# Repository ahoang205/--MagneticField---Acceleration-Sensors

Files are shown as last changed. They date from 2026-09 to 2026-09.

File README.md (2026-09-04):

# 🧭 Cảm Biến Từ Trường & Gia Tốc Đo Xa Không Dây (Low-Power Wireless Magnetic & Acceleration Sensing System)







Dự án thiết kế hệ thống phần cứng và phần mềm nhúng (Embedded IoT System) công suất thấp dùng để đo đạc, thu thập dữ liệu **Từ Trường 3 Trục** và **Gia Tốc / Góc Quay 6 Trục**, truyền dữ liệu đo từ xa qua mạng không dây **Wi-Fi Telemetry** về máy chủ giám sát.

---

## ⚡ Tính Năng Hệ Thống (Key Features)

- **Cảm Biến Từ Trường Độ Chính Xác Cao:** Tích hợp chip **MMC5983MA** (3-Axis Magnetometer) đo từ trường trái đất và phát hiện các biến đổi từ tính nhạy bén.
- **Cảm Biến Gia Tốc & Góc Quay Chuẩn Ô Tô:** Tích hợp IMU 6 trục **ASM330LHHTR** (Automotive Grade 6-axis IMU) đo gia tốc tuyến tính và vận tốc góc cực kỳ ổn định.
- **Khóa Mạch Công Suất Thấp (Low-Power Design):** Quản lý nguồn thông minh tối ưu điện năng tiêu thụ cho các thiết bị đo đạc chạy pin / năng lượng mặt trời.
- **Truyền Dữ Liệu Không Dây (Wi-Fi Telemetry):** Vi điều khiển **ESP32** đóng vai trò thu thập dữ liệu qua chuẩn truyền thông **I2C/SPI** và phát dữ liệu Telemetry liên tục qua Wi-Fi.

---

## 🧩 Sơ Đồ Khối Hệ Thống (System Architecture)

```mermaid
flowchart LR
    subgraph Sensors["Hệ Thống Cảm Biến"]
        S1["MMC5983MA (Từ Trường 3 Trục)"]
        S2["ASM330LHHTR (Gia Tốc & Gyro 6 Trục)"]
    end

    subgraph MCU["Xử Lý & Truyền Thông"]
        E1["ESP32 Microcontroller"]
        E2["Mạch Quản Lý Nguồn Năng Lượng Thấp"]
    end

    subgraph Output["Giám Sát Từ Xa"]
        W1["Mạng Wi-Fi Telemetry"]
        D1["Web Dashboard / Server Giám Sát"]
    end

    S1 -- "I2C Bus" --> E1
    S2 -- "I2C / SPI" --> E1
    E2 -- "Power Supply (3.3V)" --> E1
    E1 -- "UDP / MQTT / HTTP Telemetry" --> W1
    W1 --> D1
```

---

## 📊 Thông Số Kỹ Thuật (Specifications)

| Thông Số (Parameter) | Giá Trị (Value) | Ghi Chú (Notes) |
| :--- | :--- | :--- |
| **Vi Điều Khiển Main MCU** | `ESP32 / ESP32-WROOM-32` | Tích hợp Wi-Fi 802.11 b/g/n & Bluetooth |
| **Cảm Biến Từ Trường** | `MMC5983MA` | 0.5 mG resolution, ±8 Gauss FSR |
| **Cảm Biến IMU 6 Trục** | `ASM330LHHTR` | 3-axis Accel + 3-axis Gyro (Automotive) |
| **Chuẩn Truyền Thông Nối Tiếp** | `I2C (400kHz Fast Mode) / SPI` | Giao tiếp độ tin cậy cao |
| **Điện Áp Cấp (VCC)** | `3.3V DC` | Tích hợp LDO điện áp thấp |
| **Phần Mềm EDA Thiết Kế PCB** | `KiCad v6 / v7 / v8` | Sẵn file `.kicad_sch` & `.kicad_pcb` |

---

## 📂 Cấu Trúc Thư Mục Dự Án (Repository Structure)

```text
Magnetic_field_&_Acceleration_Sensors/
├── hardware/                         # Thiết kế phần cứng (Hardware EDA)
│   ├── schematics/                   # File bản vẽ sơ đồ nguyên lý PDF
│   │   └── schematic_Qcomment_24_12_25.pdf
│   ├── kicad/                        # Bộ file nguồn KiCad (.kicad_sch, .kicad_pcb, .kicad_pro)
│   │   ├── Low-Power Instrument.kicad_pcb
│   │   ├── Low-Power Instrument.kicad_sch
│   │   └── production/               # File Gerber gia công PCB, BOM, CPL
│   └── Dependencies/                 # Thư viện footprint & 3D STEP linh kiện
│       ├── ul_MMC5983MA/             # 3D Model & Footprints cảm biến từ trường
│       └── ul_ASM330LHHTR/           # 3D Model & Footprints cảm biến gia tốc
├── firmware/                         # Mã nguồn vi điều khiển kép (Dual MCU)
│   ├── stm32_firmware/               # Mã nguồn STM32L4xx HAL đọc mẫu cảm biến I2C/UART
│   │   ├── Core/Src/main.c           # Chương trình chính xử lý mẫu từ trường & IMU
│   │   └── supercap_test.ioc         # File cấu hình chân STM32CubeMX
│   └── esp32_wifi_telemetry/         # Mã nguồn ESP32 Arduino IDE
│       └── esp32_wifi_telemetry.ino  # Code Server Web 3D Dashboard & WebSocket Telemetry
├── docs/                             # Tài liệu kỹ thuật dự án
├── .gitignore                        # Cấu hình lọc file rác KiCad & IDE
├── LICENSE                           # Giấy phép bản quyền nguồn mở MIT
└── README.md                         # Tài liệu giới thiệu dự án
```

---

## 🛠️ Hướng Dẫn Cài Đặt & Nạp Code (Installation & Flashing Guide)

### 1. Mở & Chỉnh Sửa Phần Cứng (KiCad)
1. Cài đặt phần mềm [KiCad EDA v6+](https://www.kicad.org/).
2. Mở file `hardware/kicad/Low-Power Instrument.kicad_pro` để xem sơ đồ nguyên lý và thiết kế mạch PCB 2 lớp.

### 2. Nạp Code Cho Vi Điều Khiển ESP32
1. Mở phần mềm **Arduino IDE** (hoặc VS Code với PlatformIO).
2. Thêm bo mạch ESP32 và mở file `firmware/esp32_wifi_telemetry/esp32_wifi_telemetry.ino`.
3. Cấu hình thông số Wi-Fi (SSID, Password) và bấm **Upload** để nạp code cho ESP32.

---

## 📜 Giấy Phép (License)

Dự án được phân phối dưới giấy phép [MIT License](LICENSE) - Miễn phí sử dụng, nghiên cứu và phát triển sản phẩm thương mại.

---
*Authored by **Viet Hoang Luong**.*

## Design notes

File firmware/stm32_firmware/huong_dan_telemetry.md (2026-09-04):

# HƯỚNG DẪN KẾT NỐI PHẦN CỨNG & HIỆU CHUẨN ĐIỂM KHÔNG (CALIBRATION)
**Dự án: Telemetry Từ Trường & IMU (STM32 & ESP32)**

Tài liệu này lưu trữ toàn bộ sơ đồ đấu nối dây, nguyên lý phần mềm và cẩm nang khắc phục sự cố được thống nhất trong quá trình phát triển dự án.

---

## 1. Sơ đồ đấu nối dây hệ thống (Wiring Connection)

Dưới đây là sơ đồ đấu nối hoàn chỉnh giữa mạch điều khiển STM32, ESP32, Module Relay 12V và nguồn tải LED 12V:

```text
[ Nguồn Adapter 12V ]
  (+) 12V -----------------------+-----------------------------+
  (-) GND -------+               |                             |
                 |               |                             |
                 |               |                             |
[ Module Relay 12V ]             |                             |
  VCC <----------|---------------+                             |
  GND <----------+                                             |
  IN  <-----------------------+                                |
  COM <-----------------------|--------------------------------+
  NO  ------------------------|------------------+
                              |                  |
[ Đèn LED 12V ]               |                  |
  (+) <-----------------------|------------------+
  (-) <----------+            |
                 |            |
[ Bo mạch STM32 ]|            |
  [ Cổng J4 - UART ]          |
    Chân 1 (GND) +------------+---------> Chân [ GND ] của ESP32
    Chân 3 (TX)  -----------------------> Chân [ RX2 (GPIO16) ] của ESP32
    Chân 4 (RX)  <----------------------- Chân [ TX2 (GPIO17) ] của ESP32
  [ Cổng J1 - LOAD 1 ] (Nếu kích LED bằng cổng J1)
    Chân 2 (Tải) -------------+
  [ Cổng J3 - LOAD 2 ] (Nếu kích LED bằng cổng J3)
    Chân 1 (Tải) -------------+
  [ Tụ đỏ C23 (+) ] <-------------------- Chân [ 5V / VIN ] của ESP32 (Chỉ nối khi không cắm Pin J2)
```

### Bảng chi tiết kết nối tín hiệu điều khiển:

| Thiết bị nguồn | Chân nguồn | Thiết bị đích | Chân đích | Chức năng / Lưu ý |
| :--- | :--- | :--- | :--- | :--- |
| **STM32 (J4)** | Chân 1 (GND) | **ESP32** | GND | Nối chung GND tham chiếu (Bắt buộc) |
| **STM32 (J4)** | Chân 3 (TX) | **ESP32** | RX2 (GPIO16) | Truyền gói telemetry cảm biến |
| **STM32 (J4)** | Chân 4 (RX) | **ESP32** | TX2 (GPIO17) | Nhận lệnh kích/ngắt tải LED |
| **ESP32** | 5V / VIN | **STM32** | Tụ C23 (+) | Cấp nguồn VCAP giả lập (nếu chạy debug USB) |
| **STM32 (J1)** | Chân 2 (Tải) | **Relay 12V** | IN | Tín hiệu kích mức thấp (Low-level trigger) |
| **Adapter 12V**| Cực Dương (+) | **Relay 12V** | VCC | Cấp nguồn nuôi cuộn dây relay |
| **Adapter 12V**| Cực Âm (-) | **Relay 12V** | GND | Nối chung GND hệ thống |

### Bảng chi tiết mạch lực đóng cắt tải LED:

| Thiết bị nguồn | Đường dây | Thiết bị đích | Đầu nối | Chức năng |
| :--- | :--- | :--- | :--- | :--- |
| **Adapter 12V**| Cực Dương (+) | **Relay 12V** | COM | Đường nguồn chờ |
| **Relay 12V** | Tiếp điểm NO | **Đèn LED 12V**| Dây Đỏ (+) | Cấp điện 12V khi đóng tiếp điểm |
| **Đèn LED 12V**| Dây Đen (-) | **Adapter 12V**| Cực Âm (-) | Khép kín vòng mạch tải |

---

## 2. Logic phần mềm & Nguyên lý hiệu chuẩn (Calibration)

### A. Logic kích hoạt LED/Relay:
Hệ thống sẽ bật sáng đèn LED khi thỏa mãn đồng thời 2 điều kiện:
1. Chênh lệch từ trường Z thực tế vượt ngưỡng cài đặt: $|\Delta Z - \text{Sai lệch tĩnh}| > \text{Ngưỡng cài đặt (mG)}$.
2. Mạch cảm biến phải hoàn toàn đứng yên (không bị rung lắc/chuyển động): `is_moving == false`.

### B. Hiệu chuẩn điểm không (Zero Baseline Calibration):
Do mỗi cảm biến từ trường MMC5983MA có độ lệch mặc định chế tạo khác nhau và ảnh hưởng từ trường nền xung quanh, chênh lệch tĩnh ban đầu ($\Delta Z_0$) có thể rất lớn (khoảng vài nghìn LSB ~ vài trăm mG).
* **Tự động hiệu chuẩn khi khởi động**: Trong 20 chu kỳ đo đầu tiên sau khi bật nguồn, ESP32 sẽ tự động khóa kích hoạt Relay và lấy trung bình chênh lệch từ trường làm điểm không tĩnh (`delta_z_zero`).
* **Hiệu chuẩn thủ công qua Web**: Giao diện Web GUI tích hợp nút **"HIỆU CHUẨN ĐIỂM KHÔNG"**. Khi nhấn nút, trình duyệt gửi lệnh WebSocket `CALIBRATE` tới ESP32 để gán lại điểm không tức thời bằng giá trị chênh lệch hiện tại.

---

## 3. Cẩm nang xử lý sự cố (Troubleshooting)

### Lỗi 1: Đèn LED/Relay bật sáng liên tục ngay khi cắm nguồn
* **Nguyên nhân**: Chân RX của STM32 (`PC5` - chân 4 cổng J4) bị hở mạch, lỏng dây hoặc chập GND. Code test phần cứng trên STM32 sẽ tự động bật tải LED/Relay khi chân này về mức thấp (0V).
* **Cách khắc phục**: Kiểm tra lại dây truyền tín hiệu từ **TX2 (GPIO17) của ESP32** về **chân 4 của J4 (STM32 RX)**. Hãy đảm bảo tiếp xúc tốt hoặc thay dây bus mới.

### Lỗi 2: Web không cập nhật chỉ số của cảm biến (Số liệu bằng 0)
* **Nguyên nhân**: ESP32 không nhận được bất kỳ tín hiệu UART nào từ STM32 gửi sang.
* **Cách khắc phục**:
  1. Kiểm tra xem chân **GND** giữa 2 mạch đã nối chung chưa.
  2. Tráo đổi dây nối giữa **Chân 3 cổng J4** (TX STM32) và **Chân 4 cổng J4** (RX STM32).
  3. Kiểm tra xem dây cấp nguồn giả lập VCAP (từ ESP32 VIN sang cực dương tụ đỏ C23 của STM32) có bị lỏng không.

### Lỗi 3: ESP32 bị khởi động lại liên tục hoặc treo tại màn hình bootloader
* **Nguyên nhân**: Do cắm nhầm dây UART vào các chân cấu hình khởi động của ESP32 (như GPIO12, GPIO2, GPIO0) hoặc do sụt áp nguồn cổng USB khi ESP32 bật WiFi phát AP.
* **Cách khắc phục**: 
  1. Rút toàn bộ dây kết nối tín hiệu ra, chỉ cắm cáp USB và kiểm tra xem ESP32 có khởi chạy WiFi bình thường trên Serial Monitor (115200 baud) hay không.
  2. Đổi cổng cắm USB trên máy tính (sử dụng cổng sau của PC) hoặc đổi sang một cáp USB tốt hơn để tránh sụt áp.

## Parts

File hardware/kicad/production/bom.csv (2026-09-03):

Designator | Footprint | Quantity | Value | LCSC Part #
C1, C10, C2, C3, C4, C5, C7, C8, C9 | 0805 | 9 | 22uF
C11, C12, C14, C16, C17, C18, C20, C21, C26, C27, C30, C31, C32, C33, C34, C35, C6 | 0603 | 17 | 100nF
C13, C19, C22, C28 | 0603 | 4 | 1uF
C15, C24 | 0603 | 2 | 10uF
C23 | CHP5R5L505R-TWV | 1 | 5F
C25, C29 | 0603 | 2 | 12.5pF
D1 | 0805 | 1 | Diode
FB1 | 0603 | 1 | Ferrite Bead
J1, J2, J3 | JST_VH_B2P-VH_1x02_P3.96mm_Vertical | 3 | POWER
J4 | JST_VH_B4P-VH-B_1x04_P3.96mm_Vertical | 1 | UART
J5 | PinHeader_2x03_P2.54mm_Vertical | 1 | DEBUG
J6 | JST_VH_B3P-VH-B_1x03_P3.96mm_Vertical | 1 | ADC
L1 | L_APV_ANR4020 | 1 | 1uH
L2 | L_APV_ANR4020 | 1 | 2.2uH
Q1, Q2, Q5, Q7 | PQFN-8-EP_6x5mm_P1.27mm_Generic | 4 | DON60P03
Q3, Q4, Q6, Q8 | SOT-23 | 4 | AO3400
R1 | 0805 | 1 | 100K
R10, R19, R2, R21, R22, R23, R29, R5, R7, R8 | 0603 | 10 | 100K
R11, R12, R13, R15, R16, R17 | 0603 | 6 | 4.7K
R14 | 0603 | 1 | 1.15K
R18, R27, R4, R6 | 0603 | 4 | 10K
R20, R9 | 0603 | 2 | 36.5K
R24, R28 | 0603 | 2 | 200K
R25, R26 | 2512 | 2 | 100R
R3 | 0603 | 1 | 732K
SW1, SW2 | SW_SPST_B3U-1000P | 2 | SW_Push
U1 | Texas_RWU0007A_VQFN-7_2x2mm_P0.5mm | 1 | TPS61022
U2 | WSON-10-1EP_2.5x2.5mm_P0.5mm_EP1.2x2mm_ThermalVias | 1 | TPS63900
U3 | LGA-14L_2P5X3X0P83_STM | 1 | ASM330LHHTR
U4, U5 | MMC5983MA_MEM | 2 | MMC5983MA
U6 | LQFP-64_10x10mm_P0.5mm | 1 | STM32L476RGTx
Y1 | Resonator_SMD_Murata_CSTxExxV-3Pin_3.0x1.1mm | 1 | 8Mhz
Y2 | Crystal_SMD_3215-2Pin_3.2x1.5mm | 1 | 32kHz

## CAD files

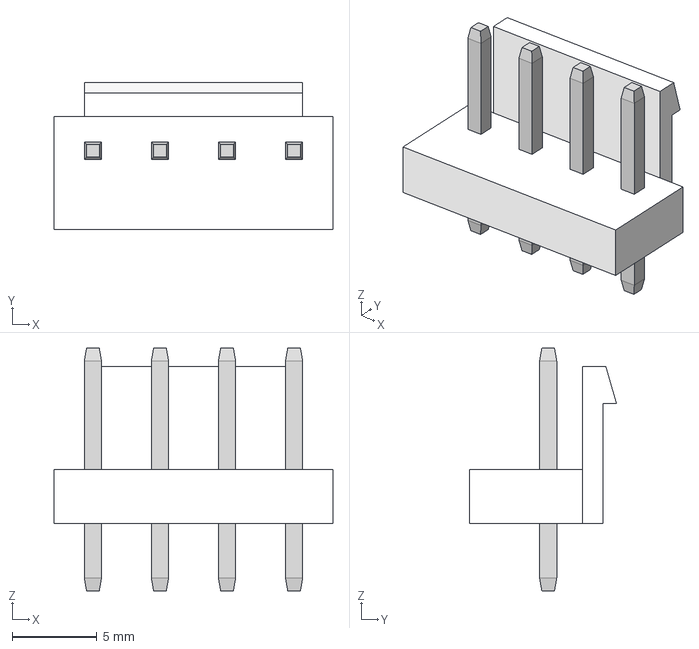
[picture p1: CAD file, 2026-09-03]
hardware/Dependencies/JST - VH - Thru (V) - 4Pin - 3.96mm.stp
16.5 x 8.69 x 14.3 mm

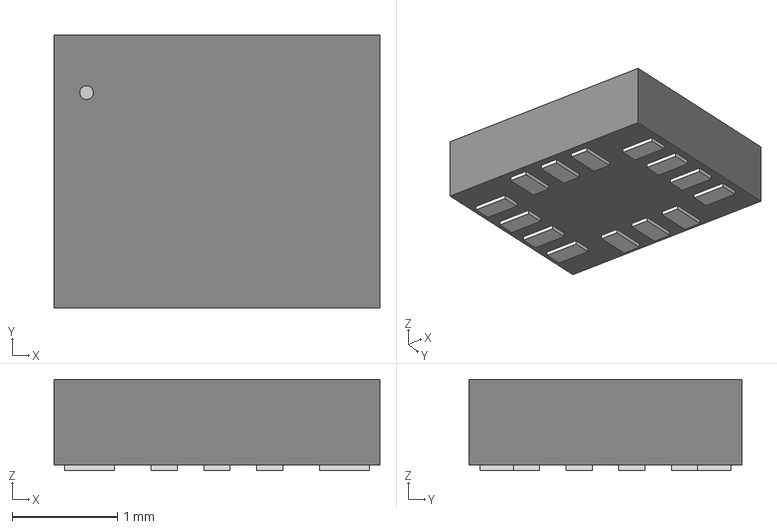
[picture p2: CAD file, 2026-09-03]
hardware/Dependencies/ul_ASM330LHHTR/LGA-14L_2P5X3X0P83_STM.step
3.10 x 2.59 x 0.866 mm

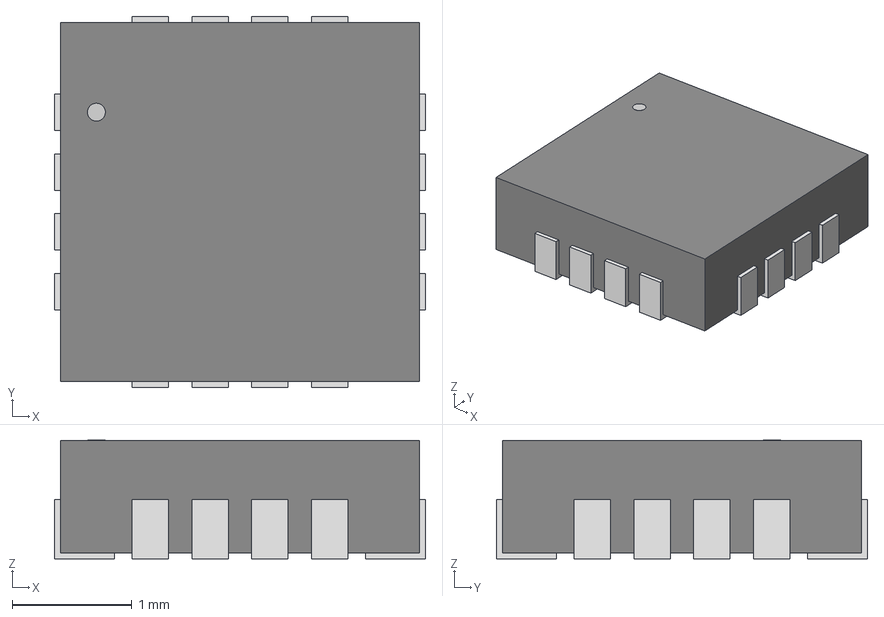
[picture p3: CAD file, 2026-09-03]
hardware/Dependencies/ul_MMC5983MA/MMC5983MA_MEM.step
3.10 x 3.10 x 0.993 mm

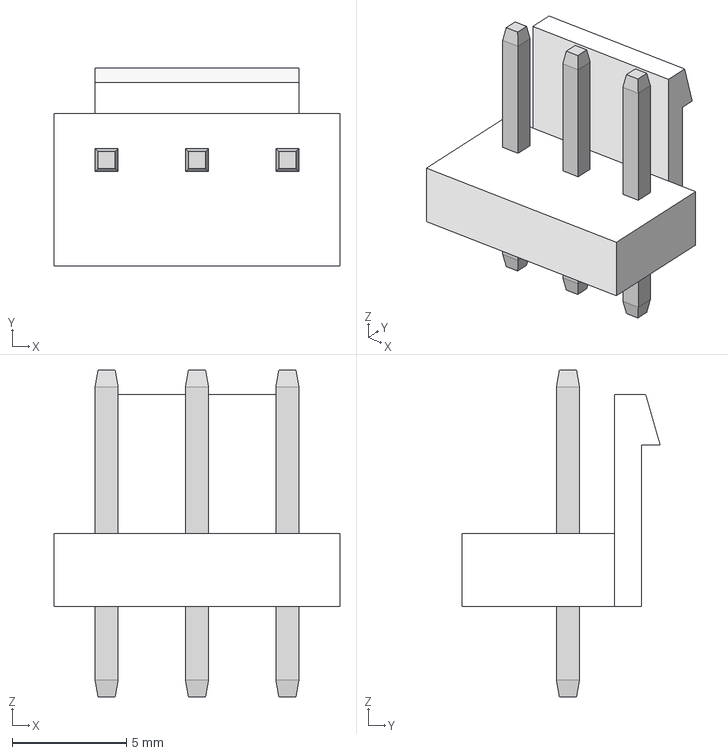
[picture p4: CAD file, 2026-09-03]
hardware/Dependencies/JST - VH - Thru (V) - 3Pin - 3.96mm.stp
12.5 x 8.69 x 14.3 mm

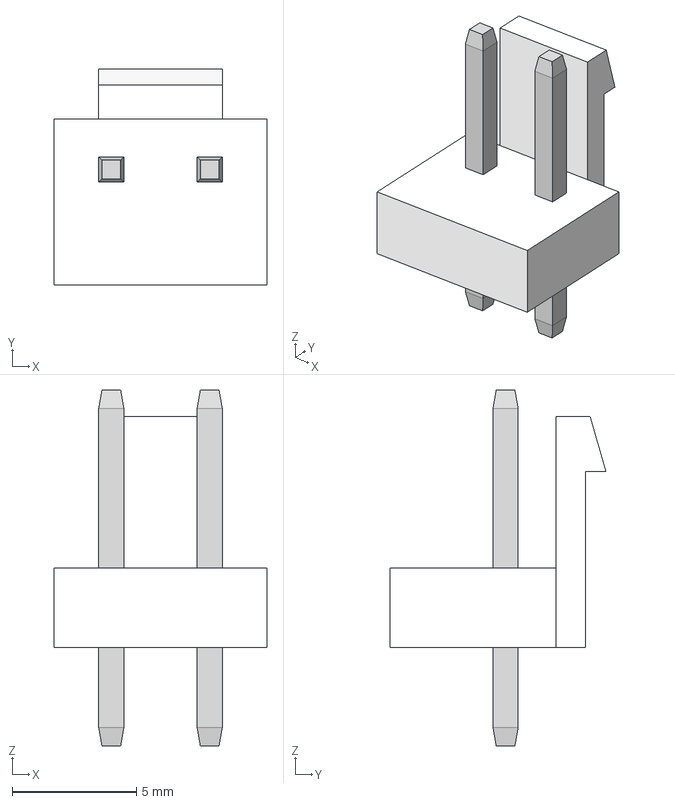
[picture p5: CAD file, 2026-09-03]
hardware/Dependencies/JST - VH - Thru (V) - 2Pin - 3.96mm.stp
8.56 x 8.69 x 14.3 mm

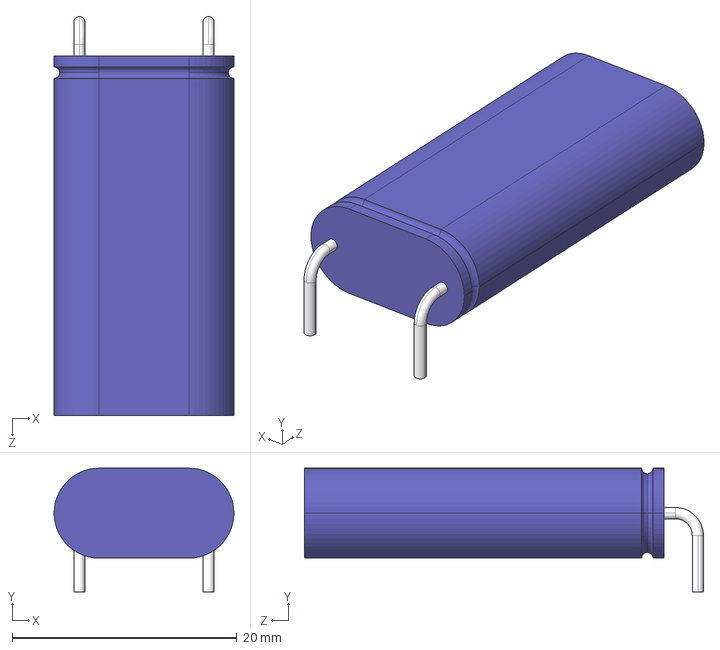
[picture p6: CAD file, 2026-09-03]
hardware/Dependencies/CHP5R5L505R-TWV.STEP
16.0 x 11.0 x 35.5 mm

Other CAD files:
hardware/Dependencies/CHP5R5L505R-TWV.SLDPRT

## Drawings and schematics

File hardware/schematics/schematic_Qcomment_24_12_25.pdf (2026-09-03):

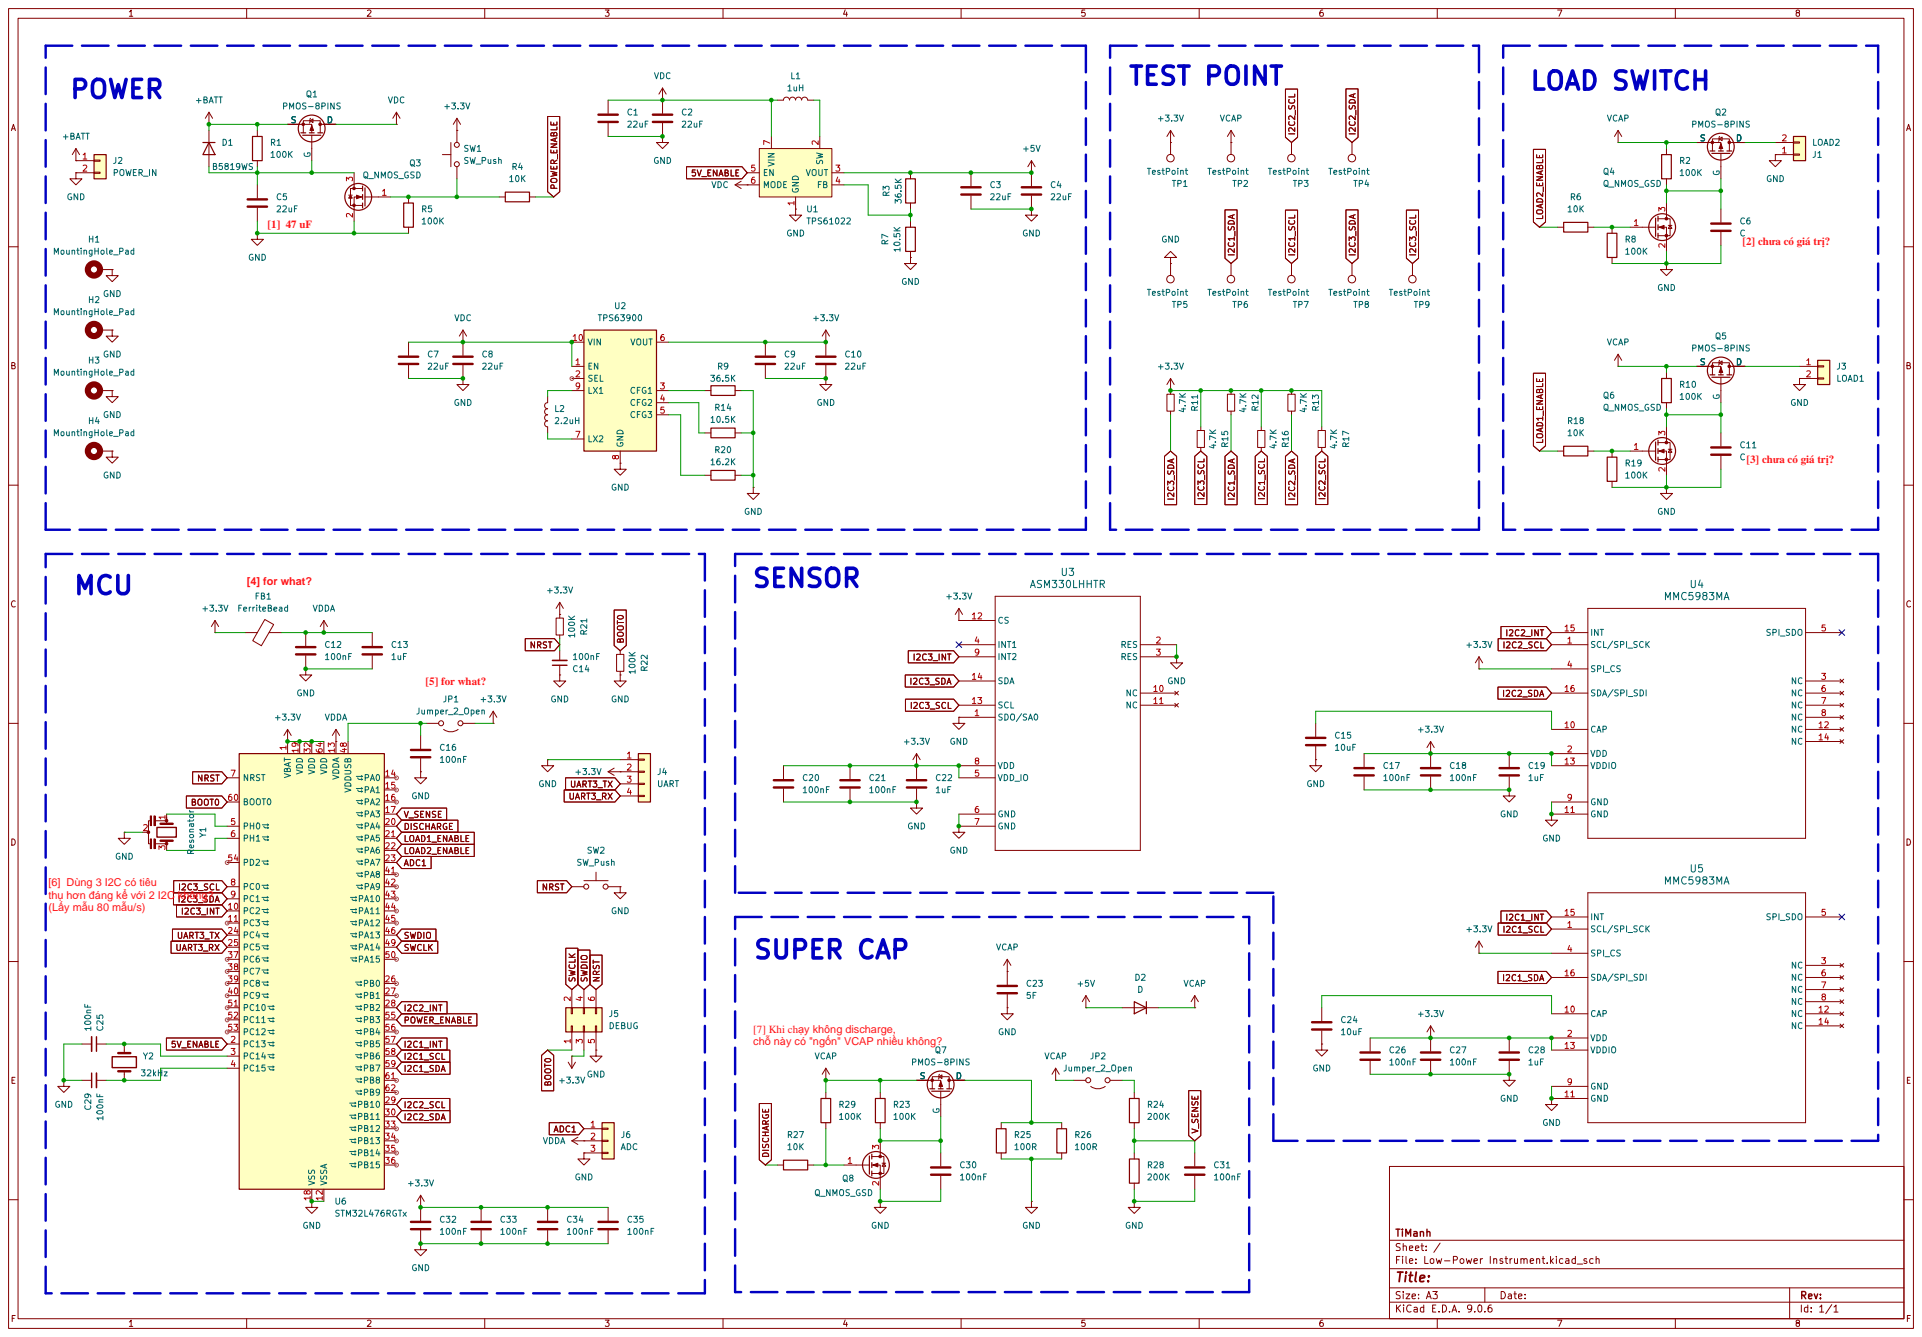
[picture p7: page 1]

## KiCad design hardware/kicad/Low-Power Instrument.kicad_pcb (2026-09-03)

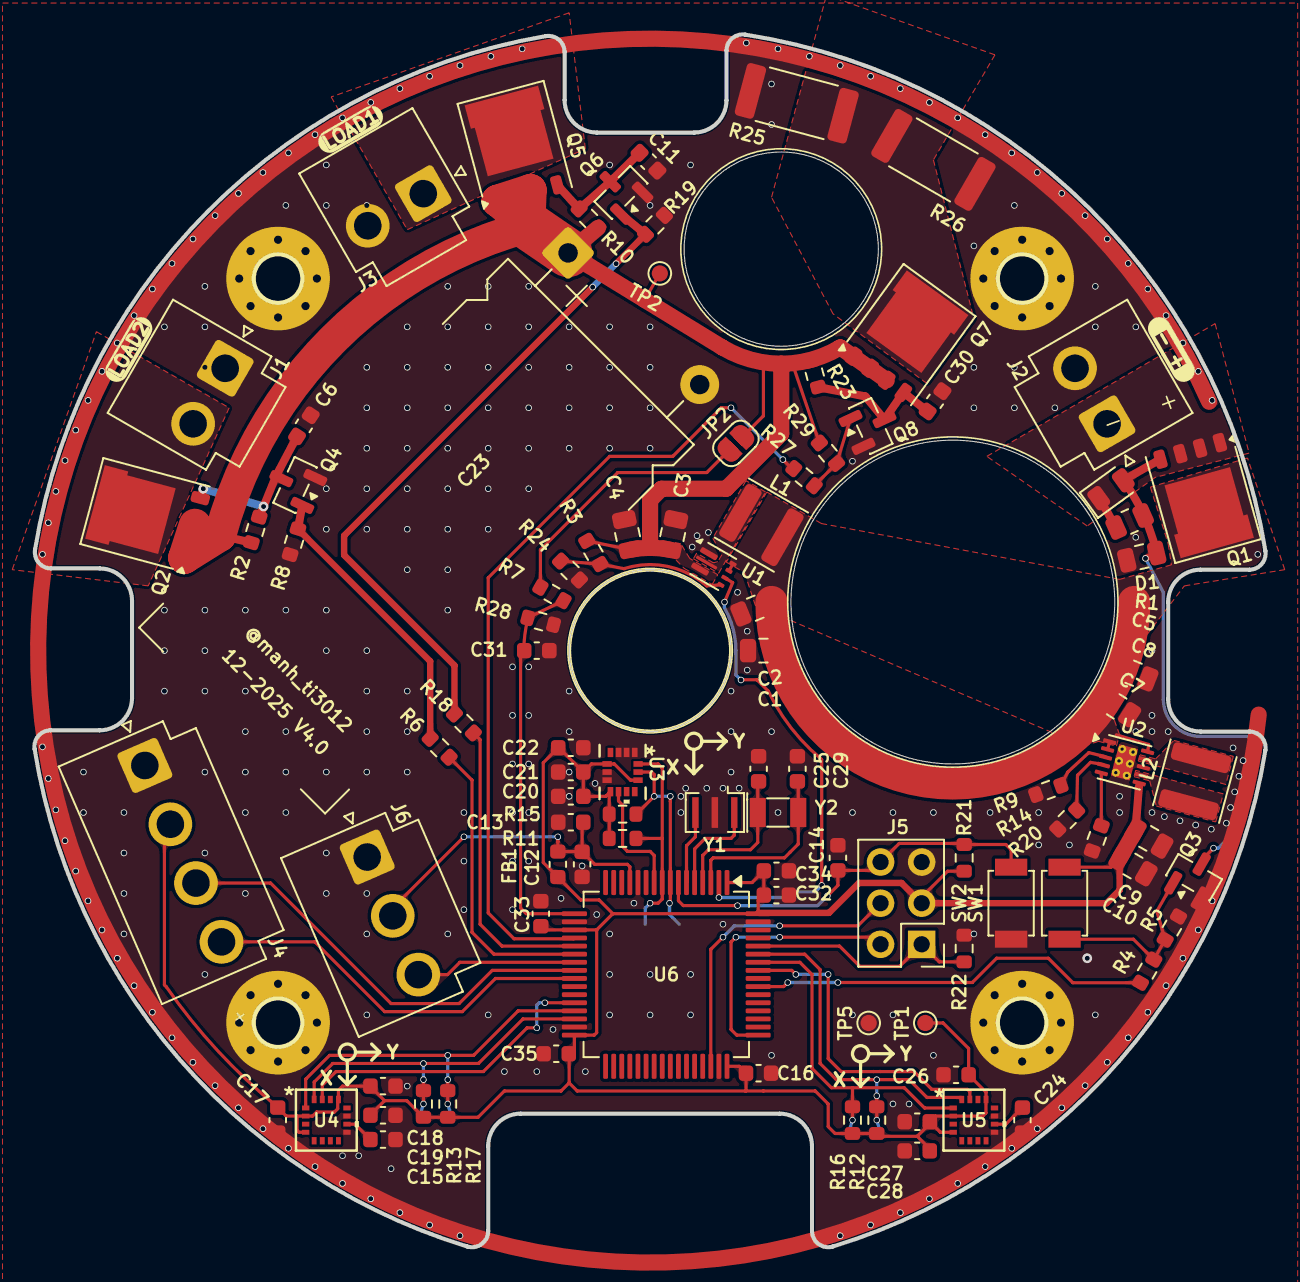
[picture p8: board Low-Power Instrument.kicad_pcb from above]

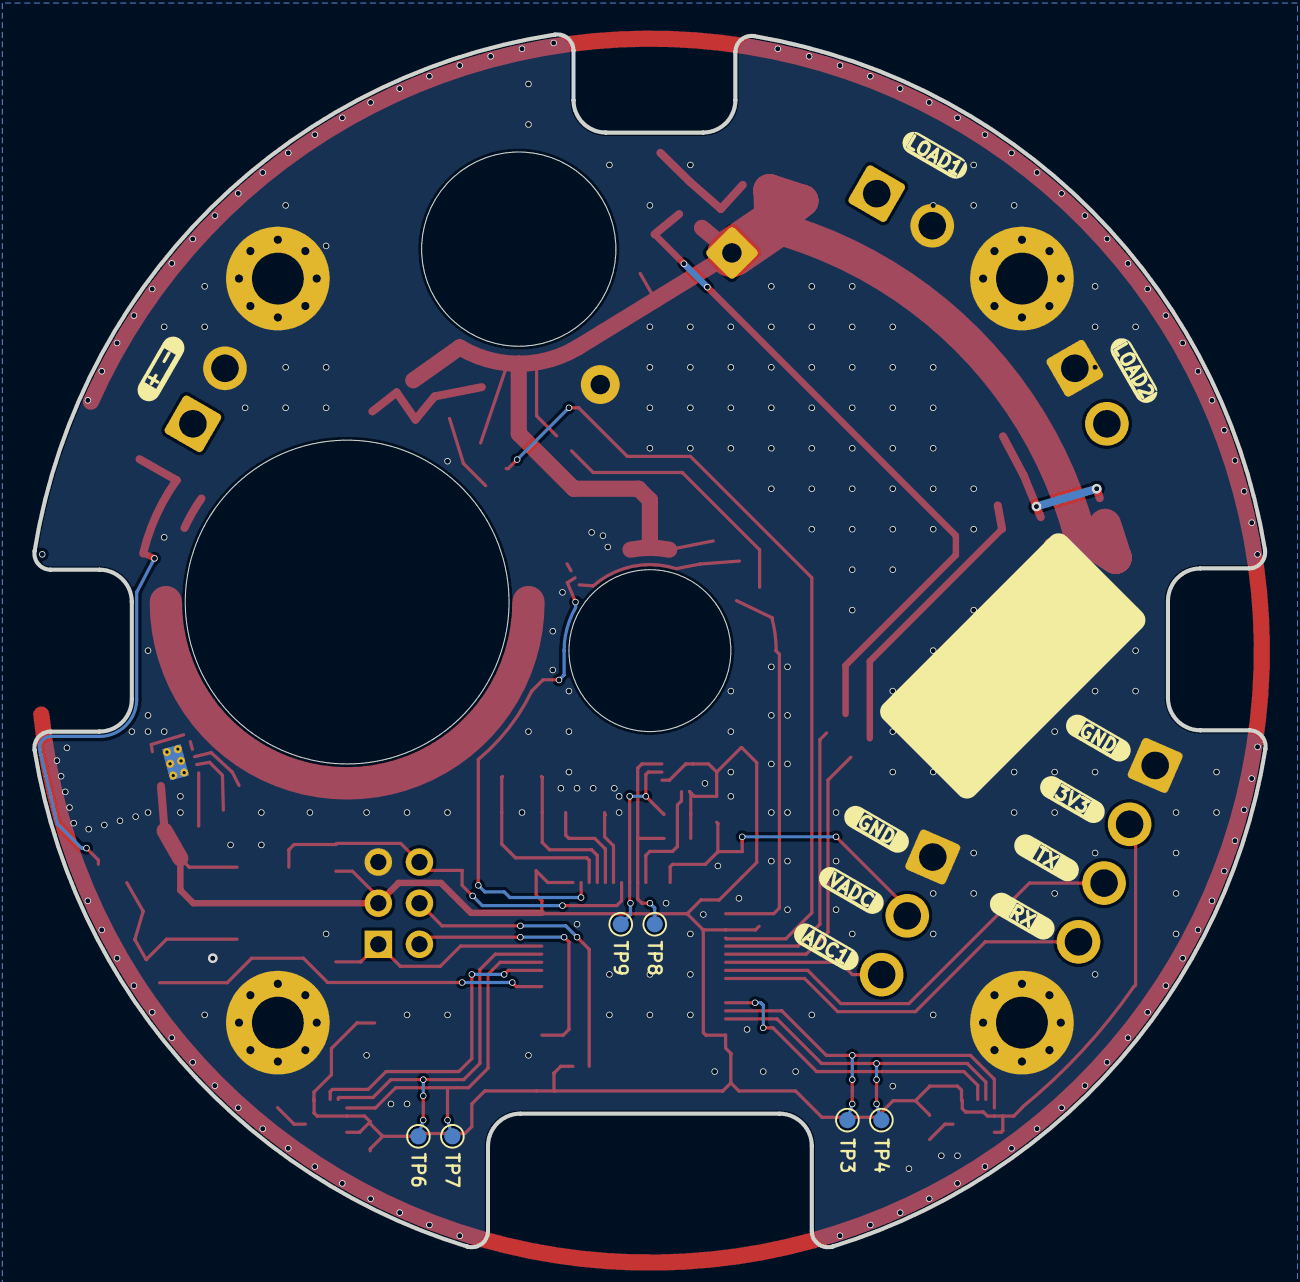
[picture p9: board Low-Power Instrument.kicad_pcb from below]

Board: 2 copper layers, 76.0 x 74.9 mm, 106 parts (6 on the bottom side), 53 nets.

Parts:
C1, C2, C3, C4, C5, C7, C8, C9, C10: 22uF; C_0805_2012Metric
C6, C11, C12, C14, C16, C17, C18, C20, C21, C26, C27, C30, C31, C32, C33, C34, C35: 100nF; C_0603_1608Metric
C13, C19, C22, C28: 1uF; C_0603_1608Metric
C15, C24: 10uF; C_0603_1608Metric
C23: 5F; CHP5R5L505R-TWV
C25, C29: 12.5pF; C_0603_1608Metric
D1: Diode; D_0805_2012Metric
FB1: Ferrite Bead; L_0603_1608Metric
H1, H2, H3, H4: MountingHole_Pad; MountingHole_3.2mm_M3_Pad_Via
J1, J2, J3: POWER; JST_VH_B2P-VH_1x02_P3.96mm_Vertical
J4: UART; JST_VH_B4P-VH-B_1x04_P3.96mm_Vertical
J5: DEBUG; PinHeader_2x03_P2.54mm_Vertical
J6: ADC; JST_VH_B3P-VH-B_1x03_P3.96mm_Vertical
JP2: Jumper_2_Open; SolderJumper-2_P1.3mm_Open_RoundedPad1.0x1.5mm
L1: 1uH; L_APV_ANR4020
L2: 2.2uH; L_APV_ANR4020
Q1, Q2, Q5, Q7: DON60P03; PQFN-8-EP_6x5mm_P1.27mm_Generic
Q3, Q4, Q6, Q8: AO3400; SOT-23
R1: 100K; R_0805_2012Metric
R2, R5, R7, R8, R10, R19, R21, R22, R23, R29: 100K; R_0603_1608Metric
R3: 732K; R_0603_1608Metric
R4, R6, R18, R27: 10K; R_0603_1608Metric
R9, R20: 36.5K; R_0603_1608Metric
R11, R12, R13, R15, R16, R17: 4.7K; R_0603_1608Metric
R14: 1.15K; R_0603_1608Metric
R24, R28: 200K; R_0603_1608Metric
R25, R26: 100R; R_2512_6332Metric
SW1, SW2: SW_Push; SW_SPST_B3U-1000P
TP1, TP2, TP3, TP4, TP5, TP6, TP7, TP8, TP9: TestPoint; TestPoint_Pad_D1.0mm
U1: TPS61022; Texas_RWU0007A_VQFN-7_2x2mm_P0.5mm
U2: TPS63900; WSON-10-1EP_2.5x2.5mm_P0.5mm_EP1.2x2mm_ThermalVias
U3: ASM330LHHTR; LGA-14L_2P5X3X0P83_STM
U4, U5: MMC5983MA; MMC5983MA_MEM
U6: STM32L476RGTx; LQFP-64_10x10mm_P0.5mm
Y1: 8Mhz; Resonator_SMD_Murata_CSTxExxV-3Pin_3.0x1.1mm
Y2: 32kHz; Crystal_SMD_3215-2Pin_3.2x1.5mm

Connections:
5V_ENABLE: U1.5 (EN), U6.2 (PC13)
+3.3V: C9.1, C10.1, C16.1, C17.1, C18.1, C19.1, C20.1, C21.1, C22.1, C26.1, C27.1, C28.1, C32.1, C33.1, C34.1, C35.1, FB1.1, J4.2, J5.3, R11.2, R12.2, R13.2, R15.2, R16.2, R17.2, R21.2, SW1.2, TP1.1, U2.6 (VOUT), U3.5 (VDD_IO), U3.8 (VDD), U3.12 (CS), U4.2 (VDD), U4.4 (SPI_CS), U4.13 (VDDIO), U5.2 (VDD), U5.4 (SPI_CS), U5.13 (VDDIO), U6.1 (VBAT), U6.19 (VDD), U6.32 (VDD), U6.48 (VDDUSB), U6.64 (VDD)
+5V: C3.1, C4.1, C23.1, JP2.2 (B), Q2.1 (S), Q2.2 (S), Q2.3 (S), Q5.1 (S), Q5.2 (S), Q5.3 (S), Q7.1 (S), Q7.2 (S), Q7.3 (S), R2.1, R3.2, R10.1, R23.1, R29.2, TP2.1, U1.3 (VOUT)
+BATT: D1.1 (K), J2.1, Q1.1 (S), Q1.2 (S), Q1.3 (S), R1.1
ADC1: J6.3, U6.23 (PA7)
BOOT0: J5.1, R22.2, U6.60 (BOOT0)
DISCHARGE: R27.1, U6.20 (PA4)
GND: C1.2, C2.2, C3.2, C4.2, C5.2, C6.2, C7.2, C8.2, C9.2, C10.2, C11.2, C12.2, C13.2, C14.1, C15.2, C16.2, C17.2, C18.2, C19.2, C20.2, C21.2, C22.2, C23.2, C24.2, C25.2, C26.2, C27.2, C28.2, C29.1, C30.2, C31.2, C32.2, C33.2, C34.2, C35.2, H1.1, H2.1, H3.1, H4.1, J1.1, J2.2, J3.2, J4.1, J5.5, J6.1, Q3.2 (S), Q4.2 (S), Q6.2 (S), Q8.2 (S), R5.2, R7.1, R8.2, R9.2, R14.2, R19.2, R20.2, R22.1, R25.2, R26.2, R28.2, SW2.2, TP5.1, U1.1 (GND), U2.8 (GND), U2.11 (GND), U3.1 (SDO/SA0), U3.2 (RES), U3.3 (RES), U3.6 (GND), U3.7 (GND), U4.9 (GND), U4.11 (GND), U5.9 (GND), U5.11 (GND), U6.12 (VSSA), U6.18 (VSS), U6.31 (VSS), U6.47 (VSS), U6.63 (VSS), Y1.2
I2C1_INT: U5.15 (INT), U6.57 (PB5)
I2C1_SCL: R16.1, TP7.1, U5.1 (SCL/SPI_SCK), U6.58 (PB6)
I2C1_SDA: R12.1, TP6.1, U5.16 (SDA/SPI_SDI), U6.59 (PB7)
I2C2_INT: U4.15 (INT), U6.28 (PB2)
I2C2_SCL: R17.1, TP3.1, U4.1 (SCL/SPI_SCK), U6.29 (PB10)
I2C2_SDA: R13.1, TP4.1, U4.16 (SDA/SPI_SDI), U6.30 (PB11)
I2C3_INT: U3.9 (INT2), U6.10 (PC2)
I2C3_SCL: R15.1, TP9.1, U3.13 (SCL), U6.8 (PC0)
I2C3_SDA: R11.1, TP8.1, U3.14 (SDA), U6.9 (PC1)
LOAD1_ENABLE: R18.1, U6.21 (PA5)
LOAD2_ENABLE: R6.1, U6.22 (PA6)
NRST: C14.2, J5.6, R21.1, SW2.1, U6.7 (NRST)
unnamed: C5.1, D1.2 (A), Q1.4 (G), Q3.3 (D), R1.2
unnamed: J1.2, Q2.5 (D)
unnamed: J3.1, Q5.5 (D)
unnamed: JP2.1 (A), R24.1
unnamed: C6.1, Q2.4 (G), Q4.3 (D), R2.2
unnamed: Q3.1 (G), R4.1, R5.1, SW1.1
unnamed: Q4.1 (G), R6.2, R8.1
unnamed: C11.1, Q5.4 (G), Q6.3 (D), R10.2
unnamed: Q6.1 (G), R18.2, R19.1
unnamed: Q7.5 (D), R25.1, R26.1
unnamed: C30.1, Q7.4 (G), Q8.3 (D), R23.2
unnamed: Q8.1 (G), R27.2, R29.1
unnamed: R3.1, R7.2, U1.4 (FB)
unnamed: L1.2, U1.2 (SW)
unnamed: R9.1, U2.3 (CFG1)
unnamed: R14.1, U2.4 (CFG2)
unnamed: R20.1, U2.5 (CFG3)
unnamed: L2.2, U2.9 (LX1)
unnamed: L2.1, U2.7 (LX2)
unnamed: C15.1, U4.10 (CAP)
unnamed: C24.1, U5.10 (CAP)
unnamed: C25.1, U6.3 (PC14), Y2.2
unnamed: C29.2, U6.4 (PC15), Y2.1
unnamed: U6.5 (PH0), Y1.1
unnamed: U6.6 (PH1), Y1.3
POWER_ENABLE: R4.2, U6.55 (PB3)
SWCLK: J5.2, U6.49 (PA14)
SWDIO: J5.4, U6.46 (PA13)
UART3_RX: J4.4, U6.25 (PC5)
UART3_TX: J4.3, U6.24 (PC4)
VDC: C1.1, C2.1, C7.1, C8.1, L1.1, Q1.5 (D), U1.6 (MODE), U1.7 (VIN), U2.1 (EN), U2.2 (SEL), U2.10 (VIN)
VDDA: C12.1, C13.1, FB1.2, J6.2, U6.13 (VDDA)
V_SENSE: C31.1, R24.2, R28.1, U6.17 (PA3)

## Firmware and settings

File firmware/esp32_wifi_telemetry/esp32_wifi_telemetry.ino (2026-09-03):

/*
 * ESP32 WiFi Telemetry & Target Detector Server
 * For "Low-Power Instrument" Project
 * 
 * Hardware Connection:
 * - STM32 USART3 TX (PC4) -> ESP32 RX0 (GPIO3) [or RX2 (GPIO16)]
 * - STM32 USART3 RX (PC5) -> ESP32 TX0 (GPIO1) [or TX2 (GPIO17)]
 * 
 * Dependencies:
 * - Arduino WebSockets library by Markus Sattler (Install via Library Manager)
 */

#include <WiFi.h>
#include <WebServer.h>
#include <WebSocketsServer.h>
#include <pgmspace.h>

// ===================== CONFIGURATION =====================
const char* ap_ssid = "ESP32_Sensor_AP";
const char* ap_password = "12345678";

// Đổi thành Serial nếu cắm vào chân RX0/TX0 của ESP32 (GPIO3/GPIO1)
#define STM32_SERIAL Serial
#define DEBUG_PRINTS_ENABLED false // Đặt thành false để tắt debug print khi dùng chung cổng Serial0 (tránh xung đột nạp code và sai lệnh cho STM32)

// Các giá trị cấu hình mặc định (có thể điều chỉnh qua Web GUI)
float delta_z_max = 100.0; // Ngưỡng chênh lệch từ trường (đơn vị mG)
float tilt_limit = 15.0;    // Góc nghiêng tối đa (độ) để chống báo giả khi mạch bị đổ/lệch
bool is_moving = false;     // Trạng thái IMU đang chuyển động/rung lắc

// ===================== GLOBALS =====================
WebServer server(80);
WebSocketsServer webSocket(81);

// Dữ liệu cảm biến nhận từ STM32
int32_t mx1 = 0, my1 = 0, mz1 = 0;
int32_t mx2 = 0, my2 = 0, mz2 = 0;
int16_t ax = 0, ay = 0, az = 0;

// Các giá trị tính toán
float pitch = 0.0;
float roll = 0.0;
float yaw = 0.0;
float delta_z = 0.0;
bool is_tilted = false;
bool is_triggered = false;

// Cấu hình bù trừ sai lệch từ trường tĩnh (Hard-iron offset calibration)
float delta_z_zero = 0.0;
bool auto_calibrated = false;
int calib_samples = 0;
float calib_sum = 0.0;

unsigned long last_ws_send = 0;

// ===================== HTML WEB PAGE =====================
const char HTML_CONTENT[] PROGMEM = R"rawhtml(
<!DOCTYPE html>
<html lang="vi">
<head>
    <meta charset="UTF-8">
    <meta name="viewport" content="width=device-width, initial-scale=1.0">
    <title>Hệ Thống Telemetry Từ Trường & IMU</title>
    <!-- Google Fonts -->
    <link href="https://fonts.googleapis.com/css2?family=Outfit:wght@300;400;600;800&family=Share+Tech+Mono&display=swap" rel="stylesheet">
    <!-- Three.js -->
    <script src="https://cdnjs.cloudflare.com/ajax/libs/three.js/r128/three.min.js"></script>
    <style>
        :root {
            --bg-color: #080b11;
            --card-bg: rgba(13, 17, 28, 0.7);
            --border-color: rgba(255, 255, 255, 0.07);
            --text-primary: #f3f4f6;
            --text-secondary: #9ca3af;
            --accent-cyan: #06b6d4;
            --accent-green: #10b981;
            --accent-red: #ef4444;
            --accent-purple: #8b5cf6;
        }
        * {
            box-sizing: border-box;
            margin: 0;
            padding: 0;
        }
        body {
            background-color: var(--bg-color);
            color: var(--text-primary);
            font-family: 'Outfit', sans-serif;
            overflow-x: hidden;
            display: flex;
            flex-direction: column;
            height: 100vh;
        }
        header {
            display: flex;
            justify-content: space-between;
            align-items: center;
            padding: 15px 30px;
            background: rgba(8, 11, 17, 0.8);
            backdrop-filter: blur(10px);
            border-bottom: 1px solid var(--border-color);
            z-index: 10;
        }
        .logo-section h1 {
            font-size: 20px;
            font-weight: 800;
            letter-spacing: 1px;
            background: linear-gradient(to right, #fff, var(--accent-cyan));
            -webkit-background-clip: text;
            -webkit-text-fill-color: transparent;
        }
        .logo-section p {
            font-size: 11px;
            color: var(--text-secondary);
            text-transform: uppercase;
        }
        .conn-status {
            display: flex;
            align-items: center;
            gap: 8px;
            font-size: 13px;
            font-weight: 600;
            background: rgba(255,255,255,0.03);
            padding: 6px 14px;
            border-radius: 20px;
            border: 1px solid var(--border-color);
        }
        .conn-dot {
            width: 8px;
            height: 8px;
            background-color: var(--accent-red);
            border-radius: 50%;
            box-shadow: 0 0 8px var(--accent-red);
        }
        .conn-dot.active {
            background-color: var(--accent-green);
            box-shadow: 0 0 10px var(--accent-green);
            animation: pulse 1.5s infinite;
        }
        @keyframes pulse {
            0% { transform: scale(1); opacity: 1; }
            50% { transform: scale(1.2); opacity: 0.5; }
            100% { transform: scale(1); opacity: 1; }
        }
        .dashboard-container {
            display: flex;
            flex: 1;
            overflow: hidden;
            width: 100%;
        }
        .sidebar {
            width: 360px;
            background: var(--card-bg);
            border-right: 1px solid var(--border-color);
            padding: 25px;
            display: flex;
            flex-direction: column;
            gap: 20px;
            overflow-y: auto;
            backdrop-filter: blur(16px);
        }
        .main-view {
            flex: 1;
            display: flex;
            flex-direction: column;
            background: radial-gradient(circle at center, #111827 0%, #080b11 100%);
            position: relative;
        }
        .glass-card {
            background: rgba(255, 255, 255, 0.02);
            border: 1px solid var(--border-color);
            border-radius: 12px;
            padding: 20px;
        }
        .card-title {
            font-size: 11px;
            font-weight: 600;
            text-transform: uppercase;
            color: var(--text-secondary);
            letter-spacing: 1.5px;
            margin-bottom: 12px;
            display: flex;
            justify-content: space-between;
        }
        .stat-grid {
            display: grid;
            grid-template-cols: repeat(3, 1fr);
            gap: 10px;
        }
        .stat-box {
            background: rgba(0,0,0,0.3);
            border: 1px solid rgba(255,255,255,0.03);
            border-radius: 8px;
            padding: 10px;
            text-align: center;
        }
        .stat-label {
            font-size: 10px;
            color: var(--text-secondary);
            text-transform: uppercase;
        }
        .stat-value {
            font-family: 'Share Tech Mono', monospace;
            font-size: 16px;
            font-weight: 600;
            margin-top: 4px;
        }
        .stat-value.cyan { color: var(--accent-cyan); }
        .stat-value.purple { color: var(--accent-purple); }
        .stat-value.green { color: var(--accent-green); }
        
        .slider-group {
            display: flex;
            flex-direction: column;
            gap: 15px;
        }
        .slider-item {
            display: flex;
            flex-direction: column;
            gap: 5px;
        }
        .slider-header {
            display: flex;
            justify-content: space-between;
            font-size: 12px;
        }
        .slider-header span:last-child {
            font-family: 'Share Tech Mono', monospace;
            font-weight: 600;
            color: var(--accent-cyan);
        }
        .custom-slider {
            -webkit-appearance: none;
            width: 100%;
            height: 6px;
            border-radius: 3px;
            background: #1f2937;
            outline: none;
        }
        .custom-slider::-webkit-slider-thumb {
            -webkit-appearance: none;
            appearance: none;
            width: 16px;
            height: 16px;
            border-radius: 50%;
            background: var(--accent-cyan);
            cursor: pointer;
            box-shadow: 0 0 8px var(--accent-cyan);
            transition: transform 0.1s;
        }
        .custom-slider::-webkit-slider-thumb:hover {
            transform: scale(1.2);
        }
        
        .toggle-list {
            display: flex;
            flex-direction: column;
            gap: 10px;
        }
        .toggle-item {
            display: flex;
            justify-content: space-between;
            align-items: center;
            font-size: 12px;
        }
        .switch {
            position: relative;
            display: inline-block;
            width: 38px;
            height: 20px;
        }
        .switch input { opacity: 0; width: 0; height: 0; }
        .slider-switch {
            position: absolute;
            cursor: pointer;
            top: 0; left: 0; right: 0; bottom: 0;
            background-color: #1f2937;
            transition: .3s;
            border-radius: 34px;
            border: 1px solid var(--border-color);
        }
        .slider-switch:before {
            position: absolute;
            content: "";
            height: 14px;
            width: 14px;
            left: 2px;
            bottom: 2px;
            background-color: white;
            transition: .3s;
            border-radius: 50%;
        }
        input:checked + .slider-switch { background-color: var(--accent-cyan); }
        input:checked + .slider-switch:before { transform: translateX(18px); }

        .alarm-indicator {
            padding: 15px;
            border-radius: 10px;
            text-align: center;
            font-weight: 800;
            font-size: 18px;
            letter-spacing: 2px;
            transition: 0.3s;
            border: 1px solid var(--border-color);
        }
        .alarm-indicator.normal {
            background: rgba(16, 185, 129, 0.08);
            border-color: rgba(16, 185, 129, 0.3);
            color: var(--accent-green);
            box-shadow: inset 0 0 15px rgba(16, 185, 129, 0.1);
        }
        .alarm-indicator.triggered {
            background: rgba(239, 68, 68, 0.15);
            border-color: rgba(239, 68, 68, 0.5);
            color: var(--accent-red);
            box-shadow: inset 0 0 20px rgba(239, 68, 68, 0.2), 0 0 15px rgba(239, 68, 68, 0.2);
            animation: flash-red 1s infinite alternate;
        }
        .alarm-indicator.tilted {
            background: rgba(239, 68, 68, 0.05);
            border-color: rgba(239, 68, 68, 0.3);
            color: #f97316;
            box-shadow: inset 0 0 15px rgba(249, 115, 22, 0.1);
        }
        @keyframes flash-red {
            0% { opacity: 0.8; }
            100% { opacity: 1; }
        }

        #canvas3d {
            flex: 1;
            width: 100%;
        }
        
        .chart-container {
            height: 250px;
            background: rgba(8, 11, 17, 0.9);
            border-top: 1px solid var(--border-color);
            padding: 15px 30px;
            display: flex;
            flex-direction: column;
            z-index: 5;
        }
        .chart-header {
            display: flex;
            justify-content: space-between;
            align-items: center;
            font-size: 11px;
            color: var(--text-secondary);
            margin-bottom: 5px;
        }
        .chart-legends {
            display: flex;
            gap: 15px;
        }
        .legend-item {
            display: flex;
            align-items: center;
            gap: 6px;
        }
        .legend-color {
            width: 12px;
            height: 3px;
            border-radius: 1px;
        }
        .chart-wrapper {
            flex: 1;
            position: relative;
        }
        #scrolling-chart {
            width: 100%;
            height: 100%;
            display: block;
        }
        @media (max-width: 768px) {
            body {
                height: auto;
                overflow-y: auto;
            }
            header {
                padding: 12px 20px;
                flex-direction: column;
                gap: 8px;
                align-items: flex-start;
            }
            .logo-section h1 {
                font-size: 18px;
            }
            .dashboard-container {
                flex-direction: column;
                height: auto;
                overflow: visible;
            }
            .sidebar {
                width: 100%;
                border-right: none;
                border-bottom: 1px solid var(--border-color);
                padding: 20px 15px;
                order: 2;
            }
            .main-view {
                width: 100%;
                height: auto;
                order: 1;
            }
            #canvas3d {
                height: 300px;
                min-height: 250px;
            }
            .chart-container {
                height: 200px;
                padding: 10px 15px;
            }
        }
    </style>
</head>
<body>

    <header>
        <div class="logo-section">
            <h1>TELEMETRY DASHBOARD</h1>
            <p>Hệ Thống Cảm Biến Từ Trường & Gia Tốc Độ Trễ Thấp</p>
        </div>
        <div class="conn-status">
            <span id="status-dot" class="conn-dot"></span>
            <span id="status-text">Đang kết nối...</span>
        </div>
    </header>

    <div class="dashboard-container">
        
        <!-- BẢNG ĐIỀU KHIỂN BÊN TRÁI -->
        <div class="sidebar">
            <!-- TRẠNG THÁI HỆ THỐNG -->
            <div id="alarm-box" class="alarm-indicator normal">
                HỆ THỐNG BÌNH THƯỜNG
            </div>

            <!-- GÓC NGHIÊNG THỜI GIAN THỰC -->
            <div class="glass-card">
                <div class="card-title">GÓC NGHIÊNG IMU</div>
                <div class="stat-grid">
                    <div class="stat-box">
                        <div class="stat-label">ROLL</div>
                        <div id="val-roll" class="stat-value green">0.0°</div>
                    </div>
                    <div class="stat-box">
                        <div class="stat-label">PITCH</div>
                        <div id="val-pitch" class="stat-value cyan">0.0°</div>
                    </div>
                    <div class="stat-box">
                        <div class="stat-label">YAW</div>
                        <div id="val-yaw" class="stat-value purple">0.0°</div>
                    </div>
                </div>
            </div>

            <!-- THIẾT LẬP NGƯỠNG -->
            <div class="glass-card">
                <div class="card-title">CÀI ĐẶT NGƯỠNG KÍCH HOẠT</div>
                <div class="slider-group">
                    <div class="slider-item">
                        <div class="slider-header">
                            <span>Ngưỡng Từ Trường (mG)</span>
                            <span id="lbl-dz-max">100</span>
                        </div>
                        <input type="range" id="sld-dz-max" class="custom-slider" min="50" max="10000" step="10" value="100">
                    </div>
                    <div class="slider-item">
                        <div class="slider-header">
                            <span>Giới Hạn Góc Nghiêng (Độ)</span>
                            <span id="lbl-tilt-limit">15°</span>
                        </div>
                        <input type="range" id="sld-tilt-limit" class="custom-slider" min="5" max="45" step="1" value="15">
                    </div>
                </div>
            </div>

            <!-- CẤU HÌNH TRỤC XOAY -->
            <div class="glass-card">
                <div class="card-title">CẤU HÌNH TRỤC 3D</div>
                <div class="toggle-list">
                    <div class="toggle-item">
                        <span>Đảo ngược trục X (Pitch)</span>
                        <label class="switch">
                            <input type="checkbox" id="inv-pitch">
                            <span class="slider-switch"></span>
                        </label>
                    </div>
                    <div class="toggle-item">
                        <span>Đảo ngược trục Z (Roll)</span>
                        <label class="switch">
                            <input type="checkbox" id="inv-roll">
                            <span class="slider-switch"></span>
                        </label>
                    </div>
                    <div class="toggle-item">
                        <span>Đảo ngược trục Y (Yaw)</span>
                        <label class="switch">
                            <input type="checkbox" id="inv-yaw" checked>
                            <span class="slider-switch"></span>
                        </label>
                    </div>
                    <div class="toggle-item">
                        <span>Tráo đổi trục Pitch & Roll</span>
                        <label class="switch">
                            <input type="checkbox" id="swap-axes">
                            <span class="slider-switch"></span>
                        </label>
                    </div>
                </div>
            </div>

            <!-- THÔNG SỐ TỪ TRƯỜNG CHI TIẾT -->
            <div class="glass-card">
                <div class="card-title">GIÁ TRỊ TỪ TRƯỜNG THỰC TẾ</div>
                <div style="font-family:'Share Tech Mono', monospace; font-size:12px; display:flex; flex-direction:column; gap:6px;">
                    <div style="display:flex; justify-content:space-between;">
                        <span style="color:var(--text-secondary);">Cảm biến 1 (Z):</span>
                        <span id="val-mz1" style="color:var(--accent-cyan); font-weight:bold;">0</span>
                    </div>
                    <div style="display:flex; justify-content:space-between;">
                        <span style="color:var(--text-secondary);">Cảm biến 2 (Z):</span>
                        <span id="val-mz2" style="color:var(--accent-purple); font-weight:bold;">0</span>
                    </div>
                    <div style="display:flex; justify-content:space-between; border-top:1px solid rgba(255,255,255,0.05); padding-top:4px;">
                        <span style="color:var(--text-secondary); font-weight:600;">Chênh lệch (ΔZ):</span>
                        <span id="val-dz" style="color:#fbbf24; font-weight:bold;">0</span>
                    </div>
                    <button id="btn-calibrate" style="margin-top:8px; width:100%; padding:8px; background:rgba(6,182,212,0.15); border:1px solid var(--accent-cyan); border-radius:6px; color:var(--accent-cyan); font-weight:600; cursor:pointer; font-family:'Outfit'; font-size:11px; transition:0.2s;" onmouseover="this.style.background='rgba(6,182,212,0.3)'" onmouseout="this.style.background='rgba(6,182,212,0.15)'">HIỆU CHUẨN ĐIỂM KHÔNG</button>
                </div>
            </div>
        </div>

        <!-- PHẦN HIỂN THỊ CHÍNH -->
        <div class="main-view">
            <!-- Canvas Three.js hiển thị 3D PCB -->
            <div id="canvas3d"></div>

            <!-- ĐỒ THỊ CUỘN SÓNG PHÍA DƯỚI -->
            <div class="chart-container">
                <div class="chart-header">
                    <span>ĐỒ THỊ BIẾN THIÊN TỪ TRƯỜNG THỜI GIAN THỰC</span>
                    <div class="chart-legends">
                        <div class="legend-item">
                            <span class="legend-color" style="background:#06b6d4;"></span>
                            <span>Cảm Biến 1 (mz1)</span>
                        </div>
                        <div class="legend-item">
                            <span class="legend-color" style="background:#8b5cf6;"></span>
                            <span>Cảm Biến 2 (mz2)</span>
                        </div>
                        <div class="legend-item">
                            <span class="legend-color" style="background:#fbbf24;"></span>
                            <span>Chênh lệch (ΔZ)</span>
                        </div>
                        <div class="legend-item">
                            <span class="legend-color" style="border-top:1px dashed #ef4444; height:0;"></span>
                            <span>Đường Ngưỡng</span>
                        </div>
                    </div>
                </div>
                <div class="chart-wrapper">
                    <canvas id="scrolling-chart"></canvas>
                </div>
            </div>
        </div>

    </div>

    <script>
        // ===================== WEBSOCKETS =====================
        let socket;
        const statusDot = document.getElementById('status-dot');
        const statusText = document.getElementById('status-text');

        function connectWS() {
            const espIP = window.location.hostname || "192.168.4.1";
            socket = new WebSocket(`ws://${espIP}:81`);
            
            socket.onopen = () => {
                statusDot.className = "conn-dot active";
                statusText.innerText = "Đã kết nối";
            };

            socket.onclose = () => {
                statusDot.className = "conn-dot";
                statusText.innerText = "Mất kết nối. Đang thử lại...";
                setTimeout(connectWS, 1500);
            };
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
void loop() {
    server.handleClient();
    webSocket.loop();

    // Đọc và phân tích luồng Serial từ STM32 phi chặn (Non-blocking)
    static String rx_buffer = "";
    while (STM32_SERIAL.available()) {
        char c = STM32_SERIAL.read();
        if (c == '\n') {
            rx_buffer.trim();
            if (rx_buffer.length() > 0) {
                if (DEBUG_PRINTS_ENABLED) {
                    Serial.print("[Debug UART] Raw: ");
                    Serial.println(rx_buffer);
                }
                parseAndProcessLine(rx_buffer);
            }
            rx_buffer = "";
        } else if (c != '\r') {
            rx_buffer += c;
            if (rx_buffer.length() > 150) { // Chống tràn bộ đệm
                rx_buffer = "";
            }
        }
    }
}

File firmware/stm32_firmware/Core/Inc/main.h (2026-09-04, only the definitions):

#define V5_enable_Pin GPIO_PIN_13
#define V5_enable_GPIO_Port GPIOC
#define Discharge_Pin GPIO_PIN_4
#define Discharge_GPIO_Port GPIOA
#define Load1_enable_Pin GPIO_PIN_5
#define Load1_enable_GPIO_Port GPIOA
#define Load2_enable_Pin GPIO_PIN_6
#define Load2_enable_GPIO_Port GPIOA

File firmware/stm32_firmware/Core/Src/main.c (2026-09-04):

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
/* Includes ------------------------------------------------------------------*/
#include "main.h"
#include <stdio.h>
#include <string.h>

/* USER CODE BEGIN PD */
#define MMC5983_ADDR (0x30 << 1)
#define ASM330_ADDR  (0x6A << 1)
/* USER CODE END PD */

I2C_HandleTypeDef hi2c1;
I2C_HandleTypeDef hi2c2;
I2C_HandleTypeDef hi2c3;
UART_HandleTypeDef huart3;

void SystemClock_Config(void);
static void MX_GPIO_Init(void);
void MX_I2C1_Init(void);
void MX_I2C2_Init(void);
void MX_I2C3_Init(void);
void MX_USART3_UART_Init(void);
/* USER CODE BEGIN PFP */
HAL_StatusTypeDef MMC5983_Init(I2C_HandleTypeDef *hi2c);
HAL_StatusTypeDef MMC5983_Trigger(I2C_HandleTypeDef *hi2c);
HAL_StatusTypeDef MMC5983_Read(I2C_HandleTypeDef *hi2c, int32_t *mx, int32_t *my, int32_t *mz);
HAL_StatusTypeDef ASM330_Init(I2C_HandleTypeDef *hi2c);
HAL_StatusTypeDef ASM330_Read(I2C_HandleTypeDef *hi2c, int16_t *ax, int16_t *ay, int16_t *az);
/* USER CODE END PFP */

/**
  * @brief  The application entry point.
  * @retval int
  */
int main(void)
{
  /* MCU Configuration--------------------------------------------------------*/

  /* Latch power supply immediately as the absolute first action to avoid shutdown when switch is released */
  __HAL_RCC_GPIOB_CLK_ENABLE();
  GPIO_InitTypeDef GPIO_InitStructPower = {0};
  HAL_GPIO_WritePin(GPIOB, GPIO_PIN_3, GPIO_PIN_SET);
  GPIO_InitStructPower.Pin = GPIO_PIN_3;
  GPIO_InitStructPower.Mode = GPIO_MODE_OUTPUT_PP;
  GPIO_InitStructPower.Pull = GPIO_NOPULL;
  GPIO_InitStructPower.Speed = GPIO_SPEED_FREQ_LOW;
  HAL_GPIO_Init(GPIOB, &GPIO_InitStructPower);

  /* Reset of all peripherals, Initializes the Flash interface and the Systick. */
  HAL_Init();

  /* Configure the system clock */
  SystemClock_Config();

  /* Initialize all configured peripherals */
  MX_GPIO_Init();
  MX_I2C1_Init();
  MX_I2C2_Init();
  MX_I2C3_Init();
  MX_USART3_UART_Init();
  
  /* USER CODE BEGIN 2 */
  // Giữ chân V5_ENABLE mức HIGH để cấp nguồn cho siêu tụ
  HAL_GPIO_WritePin(GPIOC, V5_enable_Pin, GPIO_PIN_SET);
  
  // Tắt xả siêu tụ điện (DISCHARGE = LOW)
  HAL_GPIO_WritePin(GPIOA, Discharge_Pin, GPIO_PIN_RESET);
  
  // Mặc định tắt các tải (Relay/LED) ban đầu
  HAL_GPIO_WritePin(GPIOA, Load1_enable_Pin | Load2_enable_Pin, GPIO_PIN_RESET);

  // Khởi tạo các cảm biến
  MMC5983_Init(&hi2c1); // Mag 2
  MMC5983_Init(&hi2c2); // Mag 1
  ASM330_Init(&hi2c3);  // IMU
  /* USER CODE END 2 */

  /* Infinite loop */
  /* USER CODE BEGIN WHILE */
  while (1)
  {
    /* USER CODE END WHILE */

    /* USER CODE BEGIN 3 */
    // 1. Kích hoạt đo từ trường cho cả 2 cảm biến Mag
    MMC5983_Trigger(&hi2c1);
    MMC5983_Trigger(&hi2c2);
    
    // 2. Chờ 12ms để cảm biến hoàn thành đo đạc (chu kỳ đo MMC5983 là khoảng 8-10ms)
    HAL_Delay(12);
    
    // 3. Đọc dữ liệu từ trường thô
    int32_t mx1 = 0, my1 = 0, mz1 = 0;
    int32_t mx2 = 0, my2 = 0, mz2 = 0;
    MMC5983_Read(&hi2c2, &mx1, &my1, &mz1); // Mag 1 (I2C2)
    MMC5983_Read(&hi2c1, &mx2, &my2, &mz2); // Mag 2 (I2C1)
    
    // 4. Đọc dữ liệu gia tốc góc IMU
    int16_t ax = 0, ay = 0, az = 0;
    ASM330_Read(&hi2c3, &ax, &ay, &az);     // IMU (I2C3)
    
    // Bộ lọc thông thấp số (Exponential Moving Average) tối ưu cho STM32
    static float mx1_f = 0.0f, my1_f = 0.0f, mz1_f = 0.0f;
    static float mx2_f = 0.0f, my2_f = 0.0f, mz2_f = 0.0f;
    static float ax_f = 0.0f, ay_f = 0.0f, az_f = 0.0f;
    static uint8_t filter_init = 0;
    
    if (!filter_init) {
        mx1_f = (float)mx1; my1_f = (float)my1; mz1_f = (float)mz1;
        mx2_f = (float)mx2; my2_f = (float)my2; mz2_f = (float)mz2;
        ax_f = (float)ax; ay_f = (float)ay; az_f = (float)az;
        filter_init = 1;
    } else {
        const float alpha_mag = 0.20f; // Hệ số lọc từ trường (giảm nhiễu tần số cao)
        const float alpha_acc = 0.15f; // Hệ số lọc gia tốc (chống rung lắc cơ học)
        
        mx1_f = alpha_mag * mx1 + (1.0f - alpha_mag) * mx1_f;
        my1_f = alpha_mag * my1 + (1.0f - alpha_mag) * my1_f;
        mz1_f = alpha_mag * mz1 + (1.0f - alpha_mag) * mz1_f;
        
        mx2_f = alpha_mag * mx2 + (1.0f - alpha_mag) * mx2_f;
        my2_f = alpha_mag * my2 + (1.0f - alpha_mag) * my2_f;
        mz2_f = alpha_mag * mz2 + (1.0f - alpha_mag) * mz2_f;
        
        ax_f = alpha_acc * ax + (1.0f - alpha_acc) * ax_f;
        ay_f = alpha_acc * ay + (1.0f - alpha_acc) * ay_f;
        az_f = alpha_acc * az + (1.0f - alpha_acc) * az_f;
    }
    
    // 5. Định dạng chuỗi gửi telemetry đã lọc sang ESP32 qua USART3
    char tx_buf[128];
    int len = sprintf(tx_buf, "MMC1: %ld %ld %ld | MMC2: %ld %ld %ld | ACC: %d %d %d\r\n",
                      (int32_t)mx1_f, (int32_t)my1_f, (int32_t)mz1_f,
                      (int32_t)mx2_f, (int32_t)my2_f, (int32_t)mz2_f,
                      (int)ax_f, (int)ay_f, (int)az_f);
    HAL_UART_Transmit(&huart3, (uint8_t*)tx_buf, len, 100);
    
    // 6. Nhận lệnh điều khiển tải (Relay/LED) từ ESP32 qua UART3 trực tiếp bằng thanh ghi (chống treo ORE)
    if (USART3->ISR & USART_ISR_ORE) {
        USART3->ICR = USART_ICR_ORECF; // Xóa lỗi tràn bộ đệm (Overrun)
    }
    if (USART3->ISR & USART_ISR_FE) {
        USART3->ICR = USART_ICR_FECF;  // Xóa lỗi khung truyền (Framing error)
    }
    if (USART3->ISR & USART_ISR_NE) {
        USART3->ICR = USART_ICR_NECF;  // Xóa lỗi nhiễu (Noise error)
    }
    // TEST PHẦN CỨNG: Nếu chập chân RX (PC5 / J4 Pin 4) xuống GND, tự động bật LED/Relay để test tiếp xúc
    if ((GPIOC->IDR & GPIO_PIN_5) == 0) {
        HAL_GPIO_WritePin(GPIOA, Load1_enable_Pin | Load2_enable_Pin, GPIO_PIN_SET);
    }
    
    if (USART3->ISR & USART_ISR_RXNE) {
        uint8_t rx_data = (uint8_t)(USART3->RDR & 0xFF);
        if (rx_data == '1') {
            // Bật cả 2 tải để kích relay đóng đèn sáng
            HAL_GPIO_WritePin(GPIOA, Load1_enable_Pin | Load2_enable_Pin, GPIO_PIN_SET);
            HAL_UART_Transmit(&huart3, (uint8_t*)"[DEBUG] STM32 RX 1\r\n", 20, 50);
        } else if (rx_data == '0') {
            // Tắt cả 2 tải
            HAL_GPIO_WritePin(GPIOA, Load1_enable_Pin | Load2_enable_Pin, GPIO_PIN_RESET);
            HAL_UART_Transmit(&huart3, (uint8_t*)"[DEBUG] STM32 RX 0\r\n", 20, 50);
        }
    }
    
    // 7. Chờ 100ms trước khi bắt đầu chu kỳ đo tiếp theo (chu kỳ cập nhật ~8-9Hz, rất ổn định và mượt)
    HAL_Delay(100);
  }
  /* USER CODE END 3 */
}

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


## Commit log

2026-09-03 Initial commit: Standard hardware and firmware project structure
    [CHP5R5L505R-TWV.SLDPRT, CHP5R5L505R-TWV.STEP, JST - VH - Thru (V) - 2Pin - 3.96mm.stp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]
2026-09-04 Add STM32L4xx HAL firmware source (main.c, drivers, .ioc) to firmware/stm32_firmware
2026-09-04 Update README.md to document dual microcontroller architecture (STM32L4xx HAL + ESP32 Web Telemetry)

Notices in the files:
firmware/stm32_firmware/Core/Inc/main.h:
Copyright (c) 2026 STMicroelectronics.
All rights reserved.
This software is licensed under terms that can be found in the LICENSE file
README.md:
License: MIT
